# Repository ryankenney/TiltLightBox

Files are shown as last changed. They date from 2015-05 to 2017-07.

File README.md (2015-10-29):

TiltLightBox
====================

About
--------------------

TiltLightBox is a hardware/software platform we developed for an ( link) interactive exhibit at Burning Man 2015. At its core, TiltLightBox is just a bunch of durable, illuminated boxes that can detect when they're knocked over and respond with appropriate color/sound effects. They employ battery packs and cheap wifi adapters in order to centralized control of color/sound themes.

[][2]

  [1]: docs/Overview_thumb.png (Overview)
  [2]: docs/Overview.png

[][4]

  [3]: docs/Overview_TiltLightBox_thumb.png (TiltLightBox Unit)
  [4]: docs/Overview_TiltLightBox.png

[][6]

  [5]: docs/Overview_TiltLightBox-Server_thumb.png (TiltLightBox Server)
  [6]: docs/Overview_TiltLightBox-Server.png

Index
--------------------

*  [Building the Hardware]()
	* [Wiring Diagrams](docs/Wiring Diagrams.md)
*  [Testing in Web Emulator]()
* [Deploying the TiltLightBox Software to the Arduino Boxes](docs/Arduino Setup.md) (to Arduinos)
* [Deploying the TiltLightBox Software to the Raspberry Pi Server](docs/Raspberry Pi Setup.md) (to Raspberry Pi)
* [Archive](archive/README.md)

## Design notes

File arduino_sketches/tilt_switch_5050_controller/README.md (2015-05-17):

Tilt Switch 5050 Controller
==========

TODO: Docs...
----------

Pin Assignment
----------

This is presuming an Arduino Pro Mini and the RF24 library used for the NRF24L01 wireless adaptor. (Source for NRF24L01 pin assignments: [https://arduino-info.wikispaces.com/Nrf24L01-2.4GHz-HowTo](https://arduino-info.wikispaces.com/Nrf24L01-2.4GHz-HowTo))

* A1: North switch
* A2: South switch
* 2: RF Module 8 (IRQ)
* 3 (PMW): Red LED MOSFET
* 4:
* 5 (PMW): Blue LED MOSFET
* 6 (PMW): Green LED MOSFET
* 7: East switch
* 8: West switch
* 9: RF Module 3 (CE)
* 10 (SPI SS): RF Module 4 (CSN)
* 11 (SPI MOSI): RF Module 6 (MOSI)
* 12 (SPI MISO): RF Module 7 (MISO)
* 13 (SPI SCK): RF Module 5 (SCK)

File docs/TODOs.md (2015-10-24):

TODOs

* (X) Collect code from laptop for arduinos
* (X) Collect code from pi for pi
* Fix/verify working code
* Fix/verify web page
* Organize directories in the working code
* Tag a good release
* Document pi compile/install
	* Install OS
	* Install Node
	* Deploy software
	* Configure auto-start
* (X) Document pi RF wiring
* Document pi button wiring
* Overview documentation
* Document local web demo deployment
* Document arduino install? (external libs at least)

* Document debounce module install?

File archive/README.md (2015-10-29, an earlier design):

Archive
==========

This directory is just a graveyard for accumulated tools and code samples.

Arduino
----------

### arduino/color_change_demo

A basic demo of color cycling on an Arduino.

### arduino/tilt_switch_5050_rf_controller_receiver

This is an example of the simplest nRF24L01 transmitter I got working. Pair this with the "_sender" module.

### arduino/tilt_switch_5050_rf_controller_sender

This is an example of the simplest nRF24L01 receiver I got working. Pair this with the "_receiver" module.

### arduino/tilt-light-box_arduino-listener

A basic demo of a receiver of TILT messages from a tilt-light-box, implemented on Arduino. This is just a demo, as TILT messages will be received by a Raspberry Pi, not an Arduino at the end of the day.

Fritzing
----------

### fritzing/arduino-uno-tilt-switch-5050-controller-shield.fzz

A sketch of a 5v Arduino used to control a 12v LED strip, each with their own independent
power supply (but a common ground). This is a modified (fixed) version of something I found
online, but I've since lost the reference to.

Eagle
----------

### eagle/r0.2.6

The first PCB I ordered. It supports a 5.5v Arduino controlling 12v LED strips. 

### eagle/r0.4.0

The PCB I brought to Burning Man 2015.

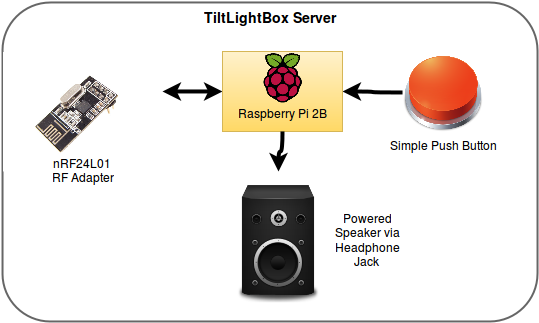
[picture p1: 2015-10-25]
docs/Overview_TiltLightBox-Server.png

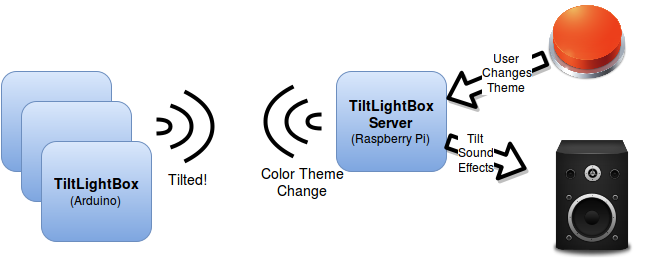
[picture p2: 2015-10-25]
docs/Overview.png

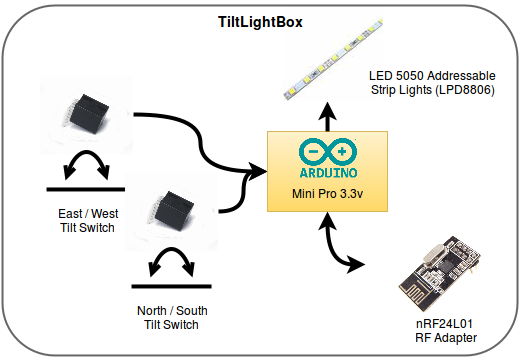
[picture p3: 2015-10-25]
docs/Overview_TiltLightBox.png

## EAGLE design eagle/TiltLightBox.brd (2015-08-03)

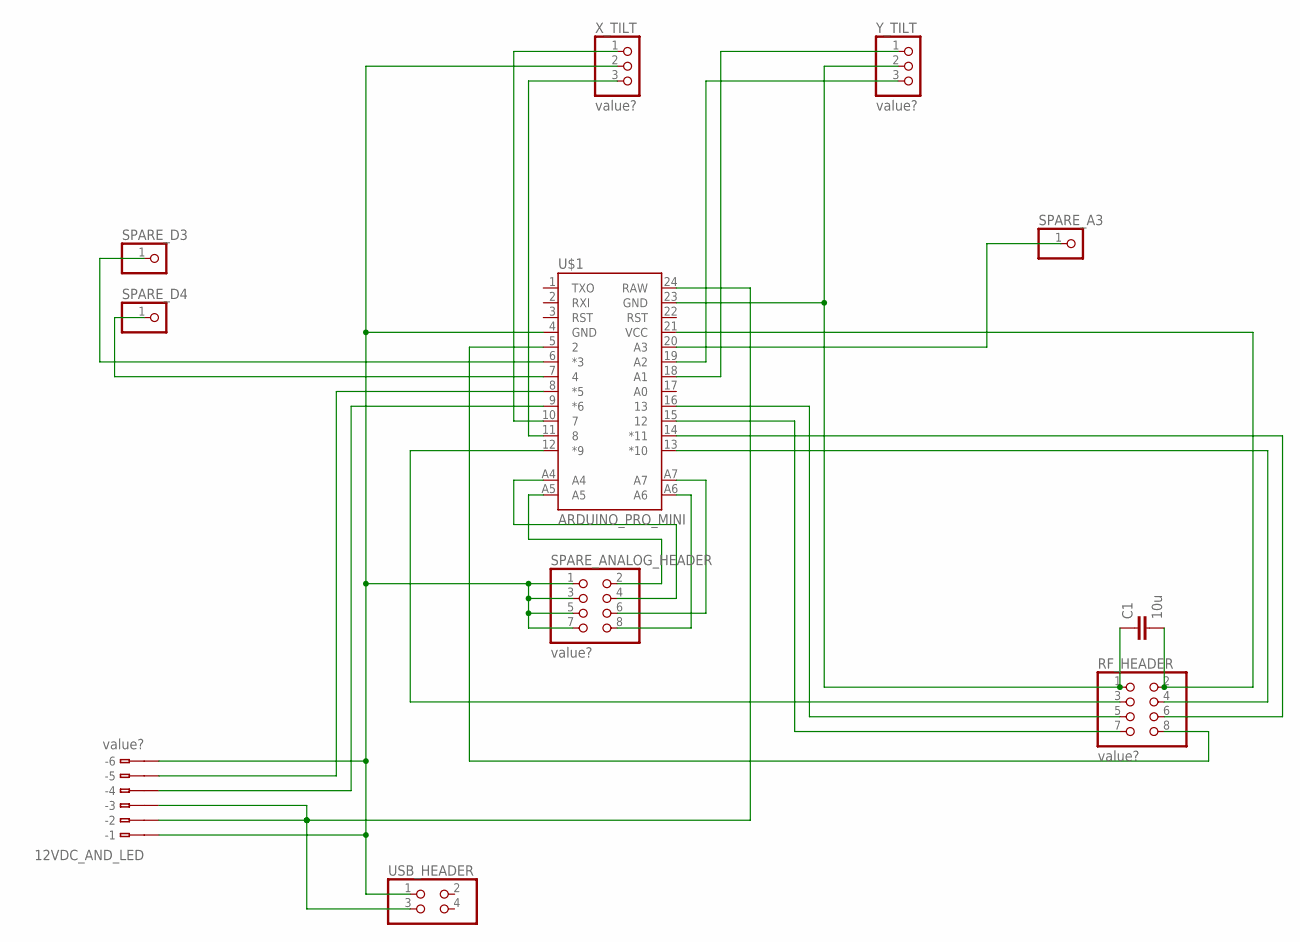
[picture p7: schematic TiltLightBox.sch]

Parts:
12VDC_AND_LED: value?; 234-206
C1: 10u; CAP-PTH-SMALL
RF_HEADER: value?; 2X04
SPARE_A3: PINHD-1X1; 1X01
SPARE_ANALOG_HEADER: value?; 2X04
SPARE_D3, SPARE_D4: PINHD-1X1; 1X01
U$1: ARDUINO_PRO_MINI
USB_HEADER: PINHD-2X2; 2X02
X_TILT: value?; 1X03
Y_TILT: value?; 1X03

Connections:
unnamed: U$1.10 (7), X_TILT.1
unnamed: 12VDC_AND_LED.B1 (B-1), 12VDC_AND_LED.B6 (B-6), SPARE_ANALOG_HEADER.1, SPARE_ANALOG_HEADER.3, SPARE_ANALOG_HEADER.5, SPARE_ANALOG_HEADER.7, U$1.4 (GND), USB_HEADER.1, X_TILT.2
unnamed: U$1.11 (8), X_TILT.3
unnamed: 12VDC_AND_LED.B5 (B-5), U$1.8 (*5)
unnamed: 12VDC_AND_LED.B2 (B-2), 12VDC_AND_LED.B3 (B-3), U$1.24 (RAW), USB_HEADER.3
unnamed: C1.1, RF_HEADER.1, U$1.23 (GND), Y_TILT.2
unnamed: 12VDC_AND_LED.B4 (B-4), U$1.9 (*6)
unnamed: SPARE_ANALOG_HEADER.4, U$1.A4
unnamed: U$1.19 (A2), Y_TILT.3
unnamed: RF_HEADER.3, U$1.12 (*9)
unnamed: RF_HEADER.4, U$1.13 (*10)
unnamed: RF_HEADER.6, U$1.14 (*11)
unnamed: SPARE_ANALOG_HEADER.2, U$1.A5
unnamed: SPARE_ANALOG_HEADER.8, U$1.A6
unnamed: SPARE_ANALOG_HEADER.6, U$1.A7
unnamed: RF_HEADER.7, U$1.15 (12)
unnamed: RF_HEADER.5, U$1.16 (13)
unnamed: RF_HEADER.8, U$1.5 (2)
unnamed: U$1.18 (A1), Y_TILT.1
unnamed: SPARE_A3.1, U$1.20 (A3)
unnamed: SPARE_D3.1, U$1.6 (*3)
unnamed: SPARE_D4.1, U$1.7 (4)
Y_TILT: C1.2, RF_HEADER.2, U$1.21 (VCC)

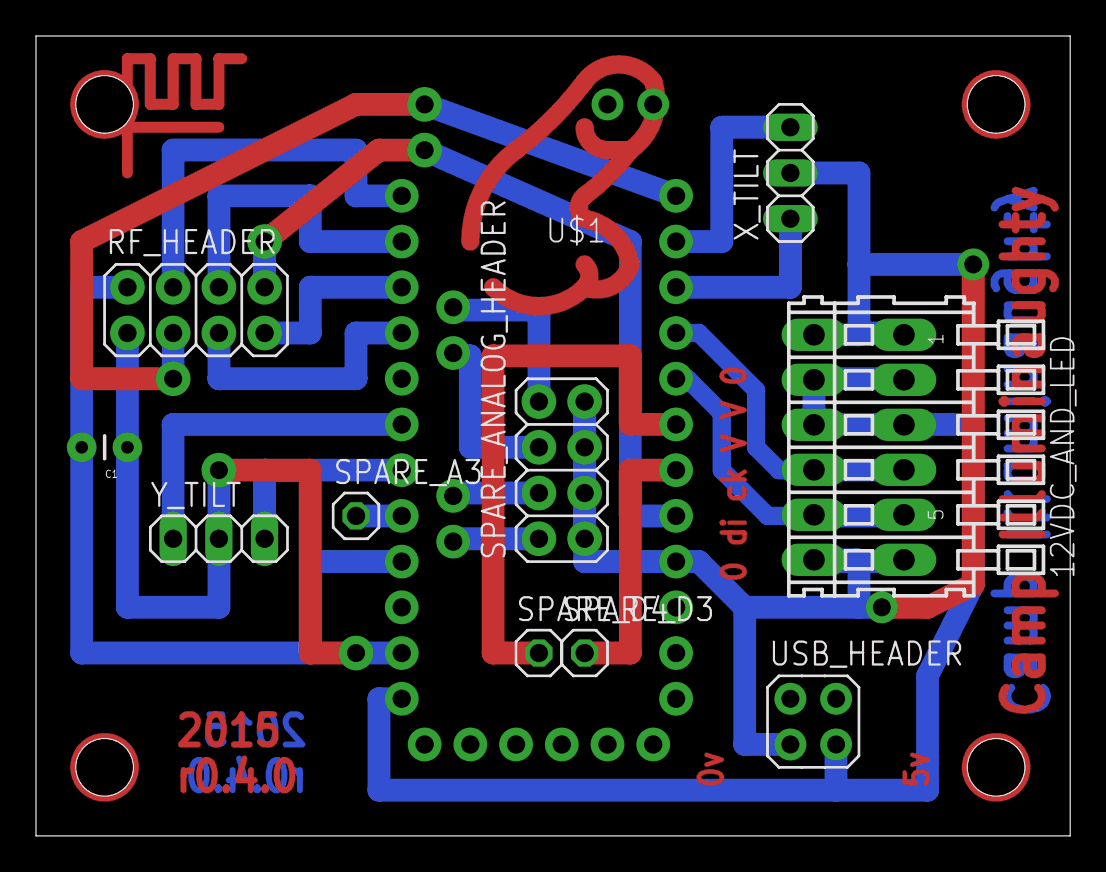
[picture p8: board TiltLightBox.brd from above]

Board: 2 copper layers, 57.5 x 44.4 mm, 11 parts (0 on the bottom side), 23 nets.

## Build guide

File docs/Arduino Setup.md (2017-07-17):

Arduino Setup for TiltLightBox
====================

Overview
--------------------

This is what I did to get load the TiltLightBox software on to my Arduino Mini Pro 3.3v devices.

Loaded Dependencies into Arduino IDE
--------------------

I forked an tagged the specific versions of the libraries we depend upon in order to ensure compatiblity, so all you need to do is clone my forks. The easiest way to get the libraries into the Arduino IDE is to git clone the repos right into your Arduino IDE libraries directory (~/sketchbook/libraries/ on linux).

It's entirely likely that the lastest versions of the modules in the upstream repos will work just fine, but here's how you get the exact versions I was using into Arduino IDE:

```
cd ~/sketchbook/libraries/
git clone -b TiltLightBox_v1.0 https://github.com/ryankenney/SPI.git 
git clone -b TiltLightBox_v1.0 https://github.com/ryankenney/RF24.git
git clone -b TiltLightBox_v1.0 https://github.com/ryankenney/FastLED.git
```

Loaded TiltLightBox into Arduino IDE
--------------------

If you havene't already, clone our repo:

```
git clone https://github.com/ryankenney/TiltLightBox.git
```

Let's call the root of that repo ```$TLB_HOME```.

You need to load the "arduino/core_logic/" directory into your Arduino IDE libraries. In linux, this is most easly accomlished with a symlink:

```
ln -s $TLB_HOME/arduino/core_logic ~/sketchbook/libraries/TiltLightBox
```

Loaded Arduino Sketch onto Arduino
--------------------

At this point, you can simply deploy this .ino file to an Arduino Mini Pro using your Arduino IDE:

```
$TLB_HOME/arduino/core_logic/tiltlightbox.ino
```

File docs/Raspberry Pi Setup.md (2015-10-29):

Setting up Rasberry Pi as TiltLightBox Server
====================

Overview
--------------------

This is what I did to get my Raspberry Pi 2 B running as the control/audio server for the TiltLightBoxes. 

Installed OS
--------------------

I just loaded the Pi with the basic NOOBS Raspian image.

Enabled SPI and I2C Kernel Modules
--------------------

Launch the Raspberry Pi config tool:

```
sudo raspbi-config
```

Select "Advanced Options"

* Select "SPI"
	* Enable the module on startup

Reboot the Pi

```
sudo reboot
```

Install libudev and build-essentials
--------------------

```
sudo aptitude install libudev-dev
sudo aptitude install build-essentials
```

Certain node dependencies rely upon the build essentials.

Installed nodejs
--------------------

> Source: [Installing node.js on Rasberry Pi](https://learn.adafruit.com/node-embedded-development/installing-node-dot-js)

Add apt.adafruit.com to your package repository list (/etc/apt/sources.list):

```
curl -sLS https://apt.adafruit.com/add | sudo bash
```

Install Node.js:

```
sudo apt-get install node
```

Verify installation:

```
$ node -v
v0.12.0
```

Downloaded/Installed TiltLightBox Application
--------------------

Get the source code:

```
sudo mkdir /opt/TiltLightBox
sudo chown pi:pi /opt/TiltLightBox/
cd /opt/
git clone https://github.com/ryankenney/TiltLightBox.git
```

Load Node.js dependencies

```
cd /opt/TiltLightBox/node
npm install nrf
```

Configured Application Auto-Start
--------------------

 Verify that this section is accurate. Written from memory.

Install forever module (monitors a Node.js process and restarts it if it dies):

```
cd /opt/TiltLightBox/node
sudo -i npm install forever -g
```

Install crontask to launch forever monitor on startup:

```
sudo crontab -u root -e
```

... adding line:

```
@reboot /usr/bin/sudo -u root -H /usr/local/bin/forever start /opt/TiltLightBox/node/TiltLightBoxServer.js >> /var/log/tiltlightbox.log 2>&1
```

Wired-Up Hardware
--------------------

See [Wiring Diagrams](Wiring Diagrams.md) for instructions on wiring up the following hardware to the Raspberry Pi:

* nRF24L01 radio antenna (for communciation with light boxes)
* push button (for change of color/sound themes)

Starting, Stopping, and Monitoring the Server
--------------------

You can see the processes that the forever module is monitoring with this (you should see TiltLightBox listed):

```
sudo forever list
```

If you kill the TiltLightBox process with ps, forever will just restart it, so here's how you properly stop the TiltLightBox process:

```
sudo forever stopall
```

(...or you could use ps to kill the forever process, then the TiltLightBox process.)

Once you kill TiltLightBox you can manually start the process in the forground with:

```
cd /opt/TiltLightBox/node
sudo node TiltLightBoxServer.js
```

If you want to launch the TiltLightBox in the background again (managed by forever), it's easiest to simply reboot.

You can see the output of forever-managed TiltLightBox process here: 

```
/var/log/tiltlightbox.log
```

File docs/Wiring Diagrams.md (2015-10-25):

Wiring Diagrams
================

Raspberry Pi Pinout
----------------

The wiring of Raspberry Pi devices can get confusing for a couple of reason.
First, they come in multiple versions. Be sure you have the right pinout diagram for you model.
Second, they have two numbering systems on each device: numbered pins and GPIO pins.
My understanding is that GPIO pins correspond to the chip pins, while the numbered pins are a Pi-specific construct.
The frustrating thing is that the plethora of libraries and sample code out there
doesn't often identify which combination of models/numbering systems they are using.

In any case, here is the pinout diagram for the model I'm using (Raspberry PI 2 B v1.1):

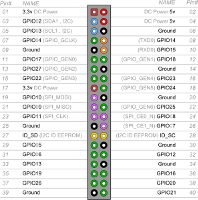
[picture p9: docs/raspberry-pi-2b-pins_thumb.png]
[][2]

  [1]: raspberry-pi-2b-pins_thumb.png (Wiring Diagram)
  [2]: raspberry-pi-2b-pins.png

Raspberry PI RF Wiring
----------------

Here is the wiring table for a Raspberry PI 2B to a nRF24L01 RF adapter:

| Pi # | Pi GPIO  | RF Pin  | My Cable |
| --- | ---  | --- | --- |
| 1 | 3.3v | VCC | Red |
| 14 | Ground | GND | Grey |
| 18 | GPIO 24  | CE | Yellow |
| 19 | GPIO 01  | MOSI | Blue |
| 21 | GPIO 09  | MISO | Brown |
| 22 | GPIO 25  | IRQ | Green |
| 23 | GPIO 11  | SCK | Purple |
| 24 | GPIO 08  | CSN | Orange |

Raspberry PI Button Wiring
----------------

 Document

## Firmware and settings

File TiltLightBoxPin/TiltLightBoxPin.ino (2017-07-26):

#include <stdio.h>
#include <stdlib.h>
#include <SPI.h>
#include <printf.h>
#include <RF24.h>
#include <tilt_light_box.h>
#include "FastLED.h"

#define NUM_LEDS 46
CRGB leds[NUM_LEDS];
const int axisPinN = A1;
const int axisPinS = A2;  
const int axisPinE = 8;
const int axisPinW = 7;
const int unusedAnalogPin = A6; // For random seed
const uint64_t pipes[2] = { 0xe7e7e7e7e7LL, 0xc2c2c2c2c2LL };
TiltBox* box;
const int RF_CE = 9;
const int RF_CSN = 10;
RF24 radio(RF_CE, RF_CSN);

void initRadio();
uint8_t readThemeChangeFromRF();
void mySleepFunc(unsigned long millis);
int myRandomValueFunc(int min, int max);
unsigned long myCurrentMillisFunc();
unsigned char myReceiveThemeChangeFunc(TiltBox *box);
bool myTiltSensorIsActiveFunc(TiltBox *box);
void myTransmitTiltStateFunc(TiltBox *box, unsigned char boxState);
void myWriteVisibleColorFunc(TiltBox *box, unsigned char r, unsigned char g, unsigned char b);

boolean wasTilted = false;
int boxId = -1;

void setup() {
  Serial.begin(9600);

  // Initialize pins
  pinMode(axisPinN, INPUT_PULLUP);
  pinMode(axisPinS, INPUT_PULLUP);
  pinMode(axisPinE, INPUT_PULLUP);
  pinMode(axisPinW, INPUT_PULLUP);

  // Initialize RF library
  initRadio();

  // Initialize tilt_light_box library
  setSleepMillisFunc(mySleepFunc);
  setRandomValueFunc(myRandomValueFunc);
  setCurrentMillisFunc(myCurrentMillisFunc);
  setReceiveThemeChangeFunc(myReceiveThemeChangeFunc);
  setTileSensorIsActiveFunc(myTiltSensorIsActiveFunc);
  setTransmitTiltStateFunc(myTransmitTiltStateFunc);
  setWriteVisibleColorFunc(myWriteVisibleColorFunc);
  box = createTiltBox();

  // Initialize random number generator from the disconnected pin (one of two rarely wired to anything on the arduino micro)
  // TODO [rkenney]: Move logic into TiltLightBox core
  randomSeed(analogRead(A4));
  boxId = random(0, 32767);
  Serial.print("Box ID: ");
  Serial.println(boxId);
}

void loop() {
  runCycle(box);
}

void initRadio() {
  radio.begin();
  
  // The following settings match our node.js "nrf" usage settings
  radio.setChannel(0x4c);
  radio.setDataRate(RF24_1MBPS);
  radio.setCRCLength(RF24_CRC_16);
  radio.setRetries(15,15);
  
  radio.enableDynamicPayloads();
  // Disabled auto-ack in order to prevent overwhelming of server broadcast
  // NOTE: We never actually verified this was a problem once we removed
  // our explicit ack messages, but things seem stable now.. so no need to change.
  radio.setAutoAck(true);
  radio.openWritingPipe(pipes[0]);
  radio.openReadingPipe(1, pipes[1]);
  radio.startListening();

  FastLED.addLeds<LPD8806, 5, 6, BRG>(leds, NUM_LEDS); 

  // This was blocking execution on my Uno for some reason
  //radio.printDetails();
}

void mySleepFunc(unsigned long millis) {
  delay(millis);
}

int myRandomValueFunc(int min, int max) {
  return random(min, max);
}

unsigned long myCurrentMillisFunc() {
  return millis();
}

void myTransmitTiltStateFunc(TiltBox *box, unsigned char boxState) {
    radio.stopListening();
    uint8_t rx_data[1] = {BOX_STATE__TILTING};
    radio.write( &rx_data, sizeof(rx_data) );
    Serial.println("Sent tilt.");
    radio.startListening();
}

unsigned char myReceiveThemeChangeFunc(TiltBox *box)  {
  // Read theme request from RF
  uint8_t rx_data[1] = {COLOR_ALG__NOOP};
  while (radio.available()) {
    int len = radio.getDynamicPayloadSize();
    if (len < 1) {
      break;
    }
    
    Serial.print("Len: ");
    Serial.println(len);

    radio.read( &rx_data, sizeof(rx_data) );
    Serial.print  ("Received theme change: ");
    Serial.print(rx_data[0]);
    Serial.print("\n");
    // Send ACK
    // NOTE: Disabled ack in order to prevent overwhelming of server broadcast
    /*
    radio.stopListening();
    radio.write( &rx_data, sizeof(rx_data) );
    Serial.println("Sent response.");
    radio.startListening();
    */
  }
  return rx_data[0];
}

void myWriteVisibleColorFunc(TiltBox *box, unsigned char r, unsigned char g, unsigned char b) {
  int i;
  for (i=0; i<NUM_LEDS; i++) {
    leds[i] = CRGB(r,g,b);
  }
  FastLED.show();
}

bool myTiltSensorIsActiveFunc(TiltBox *box) {
  bool isActive =
    pinIsActive(axisPinN) || 
    pinIsActive(axisPinS) || 
    pinIsActive(axisPinE) || 
    pinIsActive(axisPinW);
  return isActive;
}

bool pinIsActive(int pinNumber) {
  // NOTE: We invert the read value so we can make use of the
  // internal pull up resistors
  int pinValue = digitalRead(pinNumber);
  return (LOW == pinValue);
}

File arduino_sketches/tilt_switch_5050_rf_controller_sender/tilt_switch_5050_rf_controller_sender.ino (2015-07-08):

#include <LiquidCrystal.h>

#include <nRF24L01.h>
#include <RF24.h>
#include <RF24_config.h>

// RF Sender

#include <SPI.h>
#include <RF24.h>
 
#define LED 2
#define RF_CS 9
#define RF_CSN 10
RF24 radio(RF_CS, RF_CSN);
const uint64_t pipes[2] = { 0xe7e7e7e7e7LL, 0xc2c2c2c2c2LL };

const int axisPinN = A1;
const int axisPinS = A2;
const int axisPinE = 8;
const int axisPinW = 7;

int axisN = 0;
int axisS = 0;
int axisE = 0;
int axisW = 0;

uint8_t lastR = 0;
uint8_t lastG = 0;
uint8_t lastB = 0;

bool sentInitialState = false;
bool lastTransmitSucceed = false;

void setup() {
  Serial.begin(9600);
  pinMode(LED, OUTPUT);
  radio.begin();
  radio.openWritingPipe(pipes[0]);
  radio.openReadingPipe(1, pipes[1]);
  radio.startListening();
  radio.printDetails();

  pinMode(axisPinN, INPUT);
  pinMode(axisPinS, INPUT);
  pinMode(axisPinE, INPUT);
  pinMode(axisPinW, INPUT);

  // Invert pin's high/low state, and trigger use of internal pull-up resistor
  // (saves the need to add our own, external pull-down reistors)
  digitalWrite(axisPinN, HIGH);
  digitalWrite(axisPinS, HIGH);
  digitalWrite(axisPinE, HIGH);
  digitalWrite(axisPinW, HIGH);
}

/* Remove old
unsigned long packRGB(int r, int g, int b) {
  unsigned long color = 0;
  color |= a << 24;
  color |= r << 16;
  color |= g << 8;
  color |= b;
  return color;
}
*/

void loop() {

  uint8_t data[32];  // we'll transmit a 32 byte packet

  // read the state of the pushbutton value:
  axisN = digitalRead(axisPinN);
  axisS = digitalRead(axisPinS);
  axisE = digitalRead(axisPinE);
  axisW = digitalRead(axisPinW);
  if (axisN == LOW) {
    data[0] = 255;
    data[1] = 0;
    data[2] = 0;
  } else if (axisS == LOW) {
    data[0] = 0;
    data[1] = 255;
    data[2] = 0;
  } else if (axisE == LOW) {
    data[0] = 0;
    data[1] = 0;
    data[2] = 255;
  } else if (axisW == LOW) {
    data[0] = 255;
    data[1] = 0;
    data[2] = 255;
  } else {
    data[0] = 255;
    data[1] = 255;
    data[2] = 255;
  }
  if (sentInitialState && lastTransmitSucceed && data[0] == lastR && data[1] == lastG && data[2] == lastB) {
    return;
  }
  lastR = data[0];
  lastG = data[1];
  lastB = data[2];

  Serial.print("Sending color: ");
  Serial.print(data[0]);
  Serial.print(",");
  Serial.print(data[1]);
  Serial.print(",");
  Serial.print(data[2]);
  Serial.println("");

  unsigned long time = millis();
 
  // transmit the data
  radio.stopListening();
  radio.write( &data, sizeof(data) );
  radio.startListening();
  lastTransmitSucceed = false;

  // listen for acknowledgement from the receiver
  unsigned long started_waiting_at = millis();
  bool timeout = false;
  while (!radio.available() && ! timeout) {
    if (millis() - started_waiting_at > 250 ) {
      timeout = true;
    }
  }
 
  if (timeout){
    Serial.println("Failed, response timed out.");
  } else {

    sentInitialState = true;
    lastTransmitSucceed = true;

    // the receiver is just going to spit the data back
    radio.read( &data, sizeof(data) );

    digitalWrite(LED, HIGH);
    delay(100);  // light up the LED for 100ms if it worked.
    digitalWrite(LED, LOW);

    Serial.print("Got response, round trip delay: ");
    Serial.print(millis() - started_waiting_at);
    Serial.println("");
  }

}

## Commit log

2015-05-04 Added initial versions of arduino sketch, fritzing wiring diagram, and eagle pcb layout
    [First Schema.brd, First Schema.sch, arduino-uno-tilt-switch-5050-controller-shield.fzz]
2015-05-04 Added arduino-mini-pro_tilt-switch_5050-led_rf24
    [board.brd, board.sch, combined-board.brd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]
2015-05-09 Added combined-board_external-wires brd/sch * Uses arduino mini pro * Second layer is option (could just be 5 wires) * Has known bugs
    [combined-board_external-wires.brd, combined-board_external-wires.sch]
2015-05-12 * Added rf-header library * Added a couple of versions of the board
    [arduino-pro-mini_2-way-switches_v0.2.1.brd, arduino-pro-mini_2-way-switches_v0.2.1.sch, arduino-pro-mini_2-way-switches_v0.2.brd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]
2015-05-17 Added arduino sketches: * color_change_demo * tilt-switch-5050_controller
2015-05-17 Removed old tilt switch sketch (3 switches)
2015-05-17 Added arduino sketch for RF sender/receiver
2015-05-18 * Added several revisions of the board--including the version submitted for printing. * Added my own MOSFET library
    [arduino-pro-mini_2-way-switches_v0.2.2.brd, arduino-pro-mini_2-way-switches_v0.2.2.sch, arduino-pro-mini_2-way-switches_v0.2.3_trying-pull-up-resist.brd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]
2015-05-23 Added initial attempt at a js/arduino cross-compiled library
2015-05-24 Added next steps in breaking lib up. Currently has a runtime error.
2015-05-26 * Made timing info clock-based as opposed to cycle-based * Started laying the groundwork for swappable color algorithms
2015-06-02 Adjusted tilt sketch to use inverted values (pull-up resistors)
    [tilt_switch_5050_controller.ino]
2015-06-29 Tied tilt sensors to tilt_light_box library usage. Tweaked colors a bit.
2015-07-06 Moved tilt-light-box to tiltlightbox (the arduino ide is piiiicky)
2015-07-06 * Added interrupted-based ACK read to tiltlightbox_arduino_theme_sender * A couple more file renames for arduino
2015-07-07 Fixing LED pin assignments. Switching to nRF24L01 RF library. Updating while loop use use different read semantics.
    [color_change_demo.ino, tilt_switch_5050_rf_controller_sender.ino]
2015-07-07 Adding sample state change from USB signal
2015-07-27 * Fixed conflicting includes in tiltlightbox.ino ** Was preventing proper transmit to tiltlightbox_arduino_theme_sender.ino * Updated tiltlightbox_arduino_theme_sender.ino to work with the latest til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
    [tiltlightbox_arduino_theme_sender.ino, tiltlightbox_arduino_tilt_listener.ino]
2015-07-28 * Started creating board v0.4, which supports usb-power and addressable LEDs
    [r0.4.0.brd, r0.4.0.sch]
2015-07-28 Added board r0.2.6, which is the one I ordered in the first official prints of
    [r0.2.6.brd, r0.2.6.sch]
2015-07-28 * Updated tiltlightbox.ino to work with our addressable 5v leds * Fixed the radio reading loop
2015-07-29 Added finishing touches to r0.4.0 of the board
    [r0.4.0.brd, r0.4.0.sch]
2015-07-29 Updated r0.4.0 of the board: * Thickened usb header pads * Added a couple of pads for unused pins
    [r0.4.0.brd, r0.4.0.sch]
2015-08-03 Added simple demos of Raspberry Pi sound and radio usage
2015-08-19 Added server samples that work with broadcast to multiple boxes
2015-08-30 Adding all nodejs/raspberry pi files generated at Burning Man
2015-10-24 Committing what I had on my laptop after the last deployment to the Arduinos at Burning Man. It's been a while, but it looks like the web page needs fixing at a minimum.
    [tilt_light_box.cpp]
2015-10-25 Reorganized arduino sketches directory structure
2015-10-27 More cleanup... * Deleted unused node prog Button.js * Deleted log file * Deleted gitmodule RF24 (opting for manual load vi README.md) * Moved fixme.xcf into docs
2015-10-27 Archived arduino-uno-tilt-switch-5050-controller-shield.fzz
    [arduino-uno-tilt-switch-5050-controller-shield.fzz]
2015-10-27 Deleting old eagle sketches
    [First Schema.brd, First Schema.sch, arduino-pro-mini_2-way-switches_v0.2.1.brd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]
2015-10-27 Archived the r0.2.6 eagle board
    [r0.2.6.brd, r0.2.6.sch]
2015-10-29 Moved eagle board r0.4.0 to the archive
    [TiltLightBox.brd, TiltLightBox.sch, r0.4.0.brd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]
2017-07-26 Renamed arduino project to TiltLightBoxPin
2017-07-26 Fixed previous dir rename
    [TiltLightBoxServer.js]

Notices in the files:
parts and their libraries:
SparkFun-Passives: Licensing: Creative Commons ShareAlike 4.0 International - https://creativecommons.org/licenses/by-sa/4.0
